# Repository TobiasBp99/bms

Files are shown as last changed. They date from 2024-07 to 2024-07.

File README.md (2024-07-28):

# bms
Project BMS (Battery Managment System) based on Texas Instruments Applicattion note [TIDA-00792](https://www.ti.com/tool/TIDA-00792).
THe design was developed during my lessons on **_Introduction to Printed Circuit Board Design_**. 

## Overview 

The BMS is a design thought for a battery supplied product where is needed some management on battery is needed to extend its life. The whole solution it's mainly implemented with parts from the same manufacturer integrated as individual modules. 

You can check more specifics details on the [PCB report](https://github.com/TobiasBp99/bms/blob/master/reportBMS.pdf).

## Features 

- Wide voltage range up to 48V
- CAN BUS to communicate with other potential modules
- Cell voltage measure
- Pack current measure
- Temperature measure
- Cell balancing
- SOH/SOC measure
- 12 to 15 cells easily adaptable

## 3D Model
- #f03c15 `Analog Front End`
- #1589F0 `Gauge`
- #1589F0 `FET'S`
- #c5f015 `Embedded System `
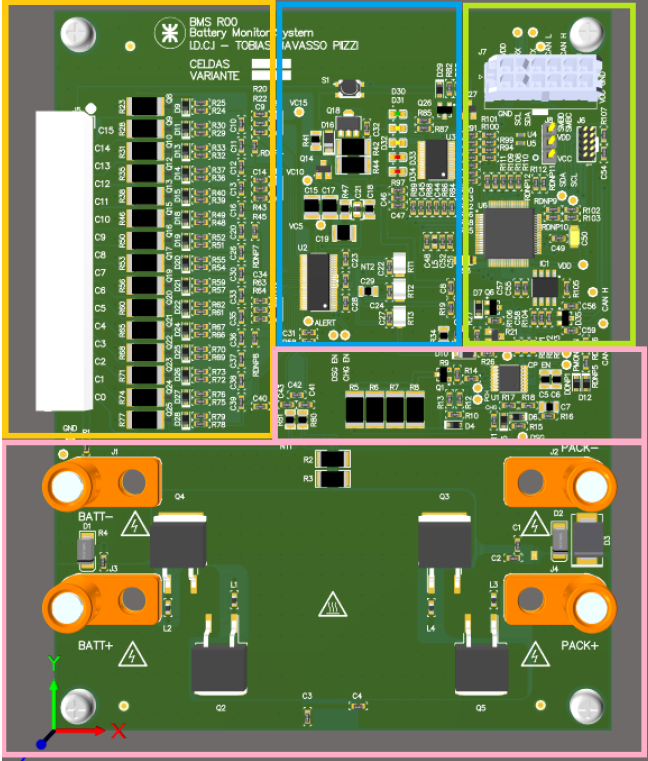
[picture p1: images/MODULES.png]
placement

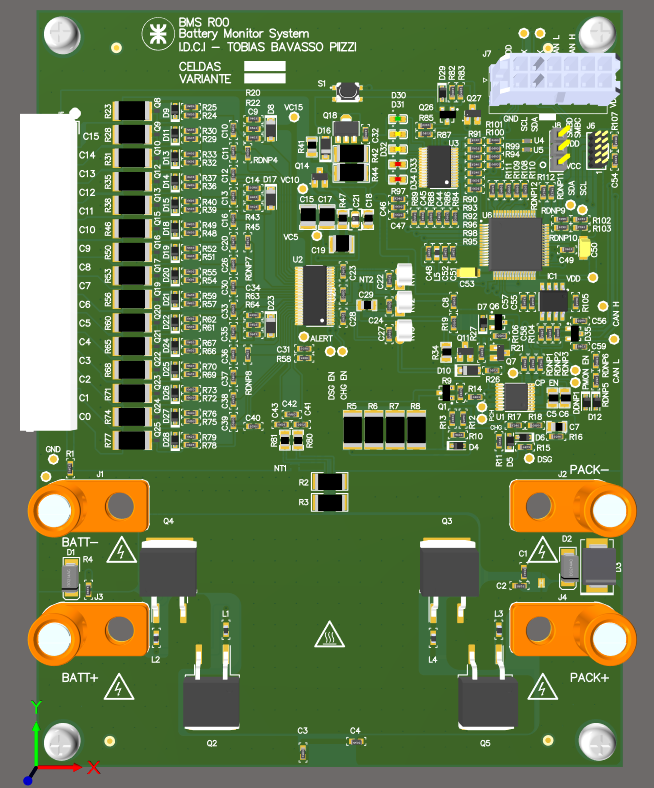
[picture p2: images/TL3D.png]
top-plane

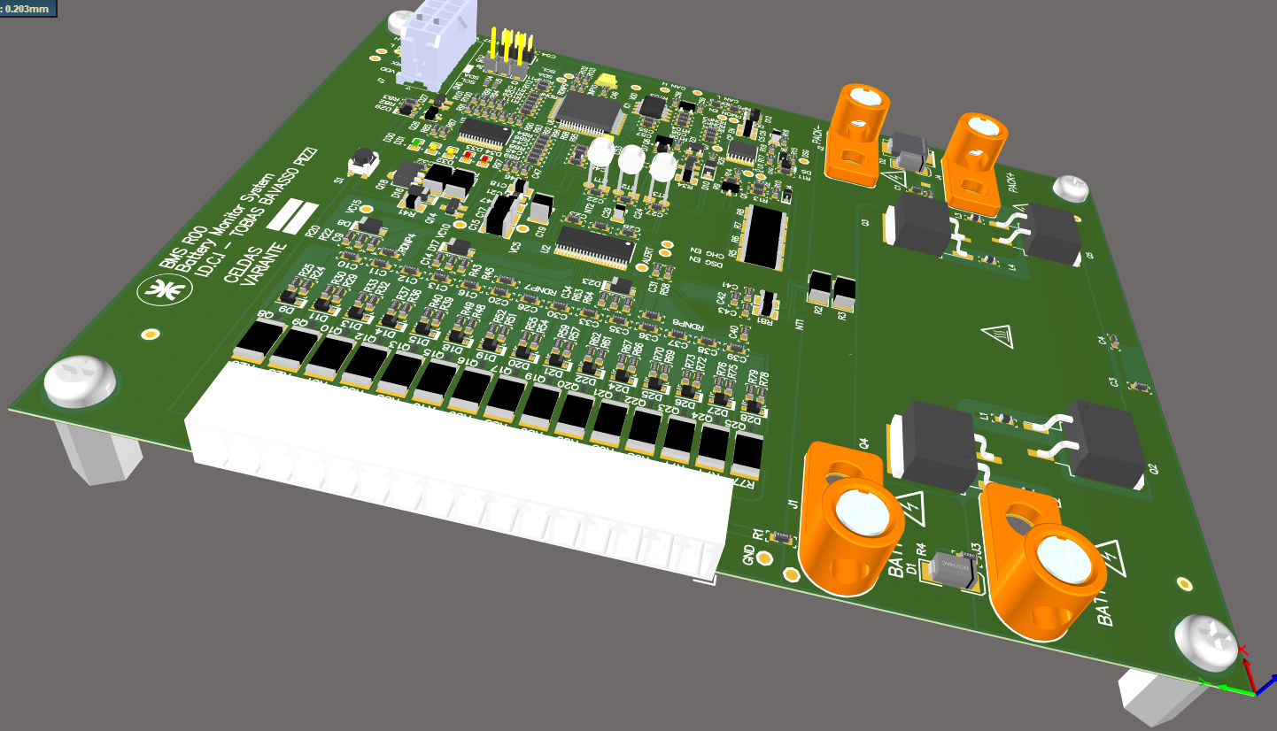
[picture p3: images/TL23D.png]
top-perspective


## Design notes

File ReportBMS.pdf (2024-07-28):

Página 1 | 21

I.D.C.I – R6575
U.T.N – F.R.B.A

# Informe de Proyecto

# “Battery Managment System”

# - Autor : Bavasso Piizzi, Tobias

# - Curso : R6575

- Docentes : Marano | , Fabio
Lozano | , Rubén

# - Curso : R6575

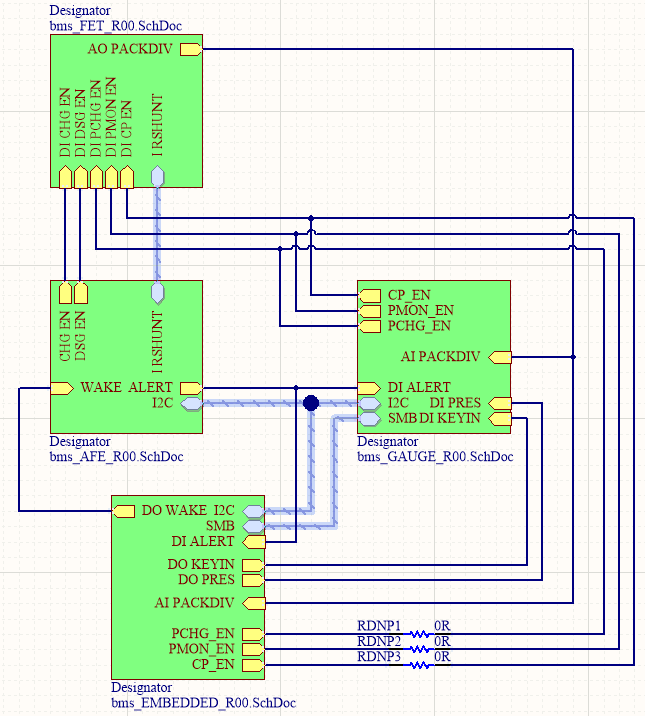
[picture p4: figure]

Página 2 | 21

# Diagrama en bloques

El diagrama en bloques de la Figura 1 corresponde al diseño del Battery Managment System (BMS), en donde se pueden identificar los bloques asociados al control de carga/descarga (FET) , front-end analógico (AFE) para el sensado del estado de cada celda, el medidor (GAUGE) encargado del procesamiento del estado de carga (SOC), estado de salud (SOH), y temperatura de la batería, al igual que el bloque del sistema embebido (EMBEDDED) para ser utilizado como gateway hacia un bus de comunicación.

Figura 1 – Diagrama en bloques

# Esquema conexionado eléctrico

El esquema eléctrico de conexionado debe conformarse mediante 4 conectores.

### Conexión Gateway

En la Figura 2, se observa al conector estipulado para operan como gateway del PCB, en donde hacia al exterior hay comunicación mediante puerto serial, protocolo I2C, Bus SMB y Bus CAN.

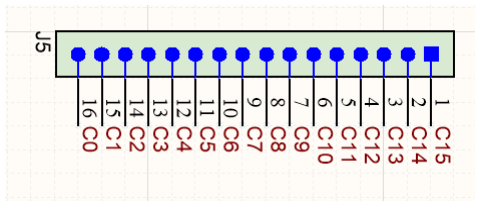
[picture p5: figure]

Página 3 | 21

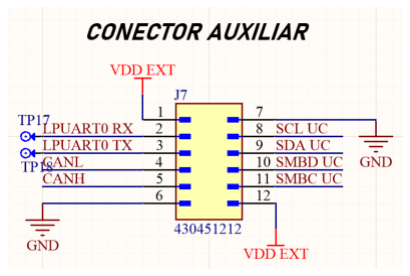
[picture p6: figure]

Figura 2 – Conector gateway

### Conexión Batería

En cuanto a las celdas de la batería tendrán un conector individualizado, en donde se tomará un cable de cada celda en serie a la batería. El diagrama de conexión se puede observar en la Figura 3.

Figura 3 – Conector celdas

### Conexión Carga

Para la carga del circuito y la batería se debe realizar el conexionado en los conectores en L o bien puede realizarse la sujeción del cable mediante un tornillo, arandela y tuerca. Estos conectores se utilizan para conectar la batería y la entrada para poder cargar la misma.

# Descripción funcional del circuito eléctrico

La funcionalidad del circuito es realizar el monitoreo para la protección de un pack de baterías de litio de 15 celdas, es decir que su tensión típica será de 48V. En este tipo de baterías es muy importante realizar constantemente la medición de su condición para evitar que su punto de trabajo sea perjudicial para prolongar su vida útil. Respecto a la funcionalidad específica de cada módulo la misma se detallará a continuación.

Página 4 | 21

### AFE

El analog front end es un nodo I2C que implementa las siguientes mediciones:
- Tensión de celda
- Corriente del pack
- Temperatura

A su vez también permite realizar el un control sobre:
- FET’s de carga y descarga
- Balanceo de cargas
Todas las mediciones realizadas son transmitidas por el bus I2C, para que los demás módulos tomen las acciones de control necesarias.

### Control de carga y descarga

Protección del tipo high-side para desconectar la batería mediante transistores en caso de haber algún inconveniente y no quitar la referencia de tensión al resto del circuito. Como características destacadas en esta etapa se pueden mencionar la carga y descarga mediante hardware independiente, al igual que la opción de realizar una pre carga a baja corriente en celdas que necesiten realizar una descarga profunda.

### Medidor

El medidor o gauge realiza todo el monitoreo de forma programable mediante SMBUS (compatilbe I2C), para no realizar el desarrollo de código en el MCU.
Este módulo se utiliza como intergaz entre el sistema embebido y el analog front end para detectar el SOC/SOH e implementar balanceos de cargas y protecciones por diversas condiciones como exceso de temperatura/tensión/corriente.
El gauge es un medidor que realiza todo el monitoreo de forma programable mediante SMBUS (compatilbe I2C), para no realizar el desarrollo de código en el MCU.

### Sistema embebido

El sistema embebido está basado en un microcontrolador que permite interconectar los módulos y otorgar una vía de salida hacia otros buses de comunicación externos.

Página 5 | 21

# BOM

El listado de partes se encuentra a continuación, para una mejor visualización se recomienda abrirlo desde el archivo generado por el software de diseño.
Com ment | Description | Designator | Footp rint | LibR ef | Qu ant ity
PIN3 | | J8 | SIP3 | PIN3 | 1
Test Point | | TP1, TP2, TP3, TP4, TP5, TP6, TP7, TP8, TP9, TP10, TP11, TP12, TP13, TP14, TP15, TP16, TP17, TP18, TP19, TP20, TP21 | TEST POINT SMD 1 | Test Point | 21
FS32 K118 LAT0 MLHT | ARM® Cortex®-M0+ series Microcontroller IC 32-Bit Single-Core 48MHz 256KB (256K x 8) FLASH 64-LQFP (10x10) | U6 | LQFP6 4-NXP | FS32 K118 LAT0 MLHT | 1
BQ76 9400 0DBT R | Battery Monitor for Lithium-Ion and Phosphate Battery Packs, DBT0044A | U2 | DBT00 44A_N | BQ76 9400 0DBT R | 1
Ferrit e Bead 1K | BLM18KG102SN1D 1K | L5 | 0603 FB | BLM1 8KG1 02SN 1D | 1
BQ76 200P WR | bq76200: Low-Power, High-Side N-channel FET Driver with Pack Voltage Monitor, PW0016A | U1 | PW00 16A_N | BQ76 200P WR | 1
1.5µF 25V X7R | Capacitor | C5 | 0805_ HV_2 | Cap 0805 _HV | 1
100n F | Capacitor | C48, C49, C51, C52, C54, C55, C57 | C0603 | Cap 0603 | 7
100n F 100V X7R | Capacitor | C1, C2, C3, C4, C46, C47 | C0603 | Cap 0603 | 6
100n F 50V X7R | Capacitor | C41, C42, C43 | C0603 | Cap 0603 | 3
100p F/50V | Capacitor | C56, C59 | C0603 | Cap 0603 | 2
10nF 100V X7R | Capacitor | C6, C7 | 0805_ HV_2 | Cap 0805 _HV | 2
10µF | Capacitor | C19 | 1210_ 270 | Cap 1210 | 1

Página 6 | 21
10µF 35V X7R | Capacitor | C15, C17 | 1210_ 270 | Cap 1210 | 2
1µF 16V X7R | Capacitor | C18 | 0805_ HV_2 | Cap 0805 _HV | 1
1µF 16V X7R | Capacitor | C21 | 0805 | Cap 0805 | 1
1µF 16V X7R | Capacitor | C23, C25, C28 | C0603 | Cap 0603 | 3
220n F 16 X7R | Capacitor | C9, C10 | C0603 | Cap 0603 | 2
220n F 16V X7R | Capacitor | C11, C12, C13, C14, C16, C20, C26, C30, C32, C33, C34, C35, C36, C37, C38, C39, C40 | C0603 | Cap 0603 | 17
3.3nF 25V X7R | Capacitor | C44, C45 | C0603 | Cap 0603 | 2
39nF | Capacitor | C58 | C0603 | Cap 0603 | 1
4.7µF 10V X7R | Capacitor | C29 | 0805_ HV_2 | Cap 0805 _HV | 1
4700 pF 50V X7R | Capacitor | C22, C24, C27 | C0603 | Cap 0603 | 3
470p F 50V X7R | Capacitor | C8, C31 | C0603 | Cap 0603 | 2
BQ78 350D BTR-R1 | CEDV Li-Ion Gas Gauge and Battery Management Controller Companion to the bq769x0 Battery Monitoring AFE, DBT0030A | U3 | DBT00 30A_N | BQ78 350D BTR-R1 | 1
L35 | Connector, L Type Copper Single Conductor, TH | J1, J2, J3, J4 | TB_L3 5 | L35 | 4
1N41 48W-7-F | Diode, Ultrafast, 100V, 0.15A, SOD-123 | D8, D10, D16, D17, D23 | SOD-123 | 1N41 48W-7-F | 5
ES3D -E3/57 T | Diode, Ultrafast, 200V, 3A, SMC | D3 | SMC | ES3D -E3/57 T | 1

Página 7 | 21
MMS Z522 8BS-7-F | Diode, Zener, 3.9 V, 200 mW, SOD-323 | D12, DDNP1 | sod-323 | MMS Z522 8BS-7-F | 2
MMS Z523 2BS-7-F | Diode, Zener, 5.6V, 200mW, SOD-323 | D9, D11, D13, D14, D15, D18, D19, D20, D21, D22, D24, D25, D26, D27, D28 | sod-323 | MMS Z523 2BS-7-F | 15
MMS Z524 6BS-7-F | Diode, Zener, 16 V, 200 mW, SOD-323 | D4, D5, D6 | sod-323 | MMS Z524 6BS-7-F | 3
MMS Z524 8BS-7-F | Diode, Zener, 18 V, 200 mW, SOD-323 | D7, D29 | sod-323 | MMS Z524 8BS-7-F | 2
NUP2 105L | Dual Line CAN Bus Protector TVS DIODE 24VWM 44VC SOT23-3 | D35 | SOT-23 | NUP2 105L | 1
TPD1 E10B 06DP YT | ESD Protection in 0402 Package with 10 pF Capacitance and 6 V Breakdown, 1 Channel, -40 to +125 degC, 2-pin X2SON (DPY) | U4, U5 | DPY00 02A | TPD1 E10B 06DP YT | 2
BLM1 8SG2 21TN 1D | Ferrite Bead, 220 ohm @ 100 MHz, 2.5 A, 0603 | L1, L2, L3, L4 | 0603 FB | BLM1 8SG2 21TN 1D | 4
Fiduc ial | Fiducial mark. There is nothing to buy or mount. | FID1, FID2, FID3, FID4 | Fiduci al10-20 | Fiduc ial_1 | 4
TJA14 41xx | High-speed CAN transceiver | IC1 | SOIC8 | TJA14 41xx | 1
LED GREE N | LED G | D30 | LED06 03-G | LED GREE N | 1
LED RED | LED R | D33, D34 | LED06 03-R | LED RED | 2
LED YELL OW | LED Y | D31, D32 | LED06 03-Y | LED YELL OW | 2
NY PMS 440 0025 PH | Machine Screw, Round, #4-40 x 1/4, Nylon, Philips panhead | H1, H2, H3, H4 | NY PMS 440 0025 PH | NY PMS 440 0025 PH | 4
4304 5121 2 | Micro-Fit 3.0 43045 CONN HEADER VERT 12POS 3MM | J7 | MOLE X_430 45121 2 | 4304 5121 2 | 1

Página 8 | 21
BSS1 23 | MOSFET, N-CH, 100V, 0.17A, SOT-23 | Q7, Q11, Q27 | SOT-23 | BSS1 23 | 3
BST8 2,215 | MOSFET, N-CH, 100 V, 0.19 A, SOT-23 | Q14 | SOT-23 | BST8 2,215 | 1
CSD1 9536 KTT | MOSFET, N-CH, 100 V, 200 A, KTT0002A | Q2, Q3, Q4, Q5 | KTT00 02A_N | CSD1 9536 KTT | 4
CSD1 3381 F4 | MOSFET, N/P-CH, 12 V, 2.1 A, 1.0x0.35x0.6mm | Q8, Q9, Q10, Q12, Q13, Q15, Q16, Q17, Q19, Q20, Q21, Q22, Q23, Q24, Q25 | YJC00 03A | CSD1 3381 F4 | 15
ZXMP 10A1 3FTA | MOSFET, P-CH, -100V, -0.6A, SOT-23 | Q1, Q6, Q26 | SOT-23 | ZXMP 10A1 3FTA | 3
HEAD ER5x 2-1.27 mm | PAD10-2X05-HH | J6 | PAD10 -2X05-HH | HEAD ER5x 2-1.27 mm | 1
10uF/ 16V | Polarized Capacitor Tantalium | C50, C53 | 1206 Cap Tant | Cap Pol Tanta lio | 2
0.0R 0.5% | Resistor | RDNP4, RDNP7, RDNP8 | R0603 | Res | 3
0R | Resistor | RDNP1, RDNP2, RDNP3, RDNP9, RDNP10, RDNP11, RDNP12 | R0603 | Res | 7
0R 0.5% | Resistor | R1, R4, R18, R98, R99 | R0603 | Res | 5
1.00K 1% | Resistor | R44 | 2010 | Res | 1
1.0K 5% | Resistor | R20, R22, R25, R30, R33, R37, R40, R43, R45, R49, R52, R55, R59, R62, R63, R64, R67, R70, R73, R76, R79, R94, R95, RDNP5, RDNP6 | R0603 | Res | 25
1.0M 5% | Resistor | R21, R96 | R0603 | Res | 2
1.0m R 1% | Resistor | R2, R3 | 2010 | Res | 2
1.2K 5% | Resistor | R5, R6, R7, R8 | 2512 | Res | 4
10.0K | Resistor | R102, R103 | R0603 | Res | 2
10.0K 0.1% | Resistor | R88, R89 | R0603 | Res | 2
10.0K 5% | Resistor | R24, R29, R32, R36, R39, R48, R51, R54, R57, R61, R66, R69, R72, R75, R78 | R0603 | Res | 15

Página 9 | 21
10.0 M 1% | Resistor | R9, R10, R11, R19, R27 | R0603 | Res | 5
100.0 K 1% | Resistor | R34, R41, R47 | 0805_ HV_2 | Res | 3
100.0 K 5% | Resistor | R82, R90, R97 | R0603 | Res | 3
100.0 R 1% | Resistor | R12, R16, R17 | R0603 | Res | 3
100.0 R 5% | Resistor | R100, R101 | R0603 | Res | 2
100R 1% | Resistor | R80, R81 | 0805_ HV_2 | Res 0805 _HV | 2
113.0 K 1% | Resistor | R93 | R0603 | Res | 1
12.0K | Resistor | R107, R108, R109, R110, R111, R112 | R0603 | Res | 6
220.0 K | Resistor | R83 | R0603 | Res | 1
28.7R 1% | Resistor | R23, R28, R31, R35, R38, R46, R50, R53, R56, R60, R65, R68, R71, R74, R77 | 2512 | Res | 15
300.0 K 25pp m/°C | Resistor | R84, R85, R86, R87 | R0603 | Res | 4
4.7K | Resistor | R105 | R0603 | Res | 1
499.0 K 1% | Resistor | R58 | R0603 | Res | 1
51.0K 5% | Resistor | R26 | R0603 | Res | 1
510.0 K 5% | Resistor | R91, R92 | R0603 | Res | 2
61.9R | Resistor | R104, R106 | R0603 | Res | 2
620.0 R 5% | Resistor | R13, R14, R15 | R0603 | Res | 3
750.0 R 5% | Resistor | R42 | 2010 | Res | 1
N/A | Spark Gap | E1 | SPARK _GAP2 | Spark Gap | 1
1902 C | Standoff, Hex, 0.5"L #4-40 Nylon | H5, H6, H7, H8 | Keysto ne_19 02C | 1902 C | 4
PTS8 15 | SWITCH TACTILE SPST-NO 0.05A 12V | S1 | PTS81 5SJK2 50SMT RLFS | PTS8 15 | 1
3950 2101 1 | Terminal block, 3.5mm, 16x1, R/A, TH | J5 | HEAD ER_39 | 3950 2101 6 | 1

Página 10 | 21
| | | 50210 16
103A T-2 | Thermistor NTC, 10.0k ohm, 1%, Disc, 5x8.4 mm | RT1, RT2, RT3 | Therm istor_1 03AT-2 | 103A T-2 | 3
ZXTN 1910 0CZT A | Transistor, NPN, 100 V, 5.25 A, SOT-89 | Q18 | SOT-89-3 | ZXTN 1910 0CZT A, Diod es Inc. | 1
SMAJ 60CA | TVS DIODE 22VWM 35.5VC DO214AC. BIDIRECCIONAL | D1, D2 | DO-214AB (SMA) | SMAJ 60CA | 2

# Hojas de datos

Los 3 (tres) circuitos integrados principales que conforman el PCB son parte del portfolio para manejo de baterías del proveedor Texas Instruments.
Se recomienda revisar la documentación más detallada del fabricante.

BQ76200
Para revisar la documentación en mayor profundidad se recomienda revisar el enlace del Datasheet. (https://www.ti.com/product/es-mx/BQ76200)

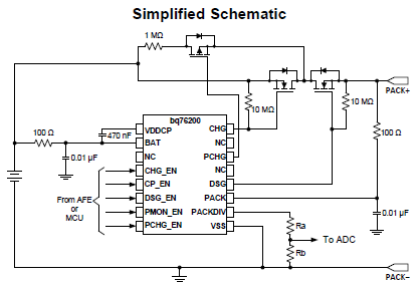
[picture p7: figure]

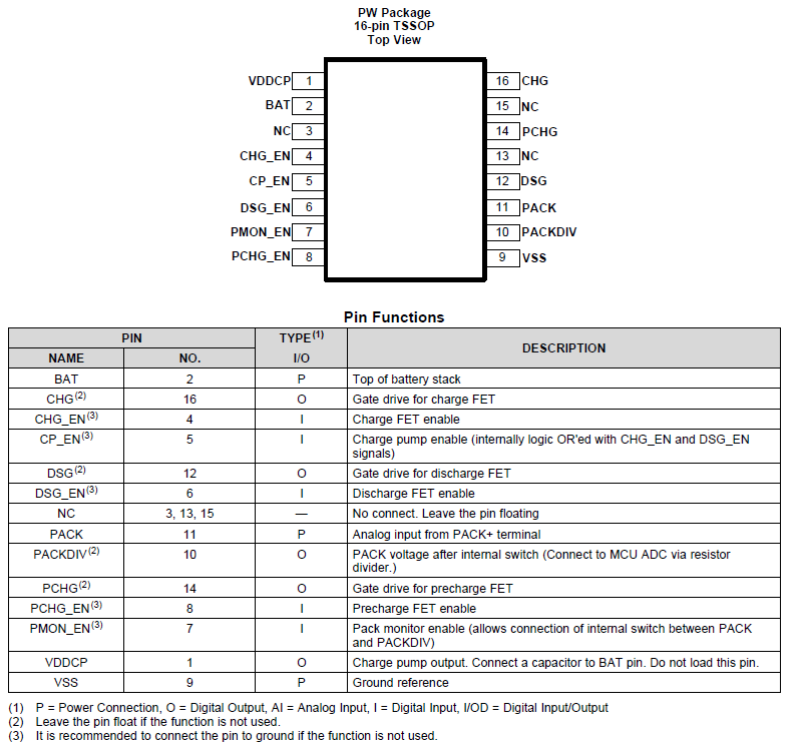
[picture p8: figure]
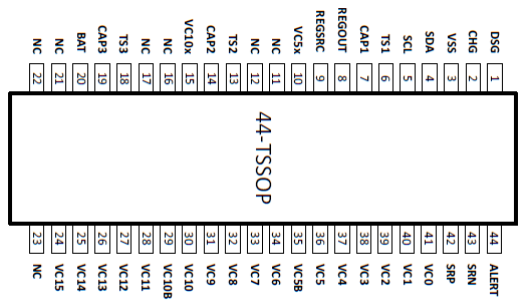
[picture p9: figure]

Página 11 | 21

Figura 4 – BQ76200 resumen datasheet BQ76940
Para revisar la documentación en mayor profundidad se recomienda revisar el enlace del Datasheet. (https://www.ti.com/product/es-mx/BQ76940)

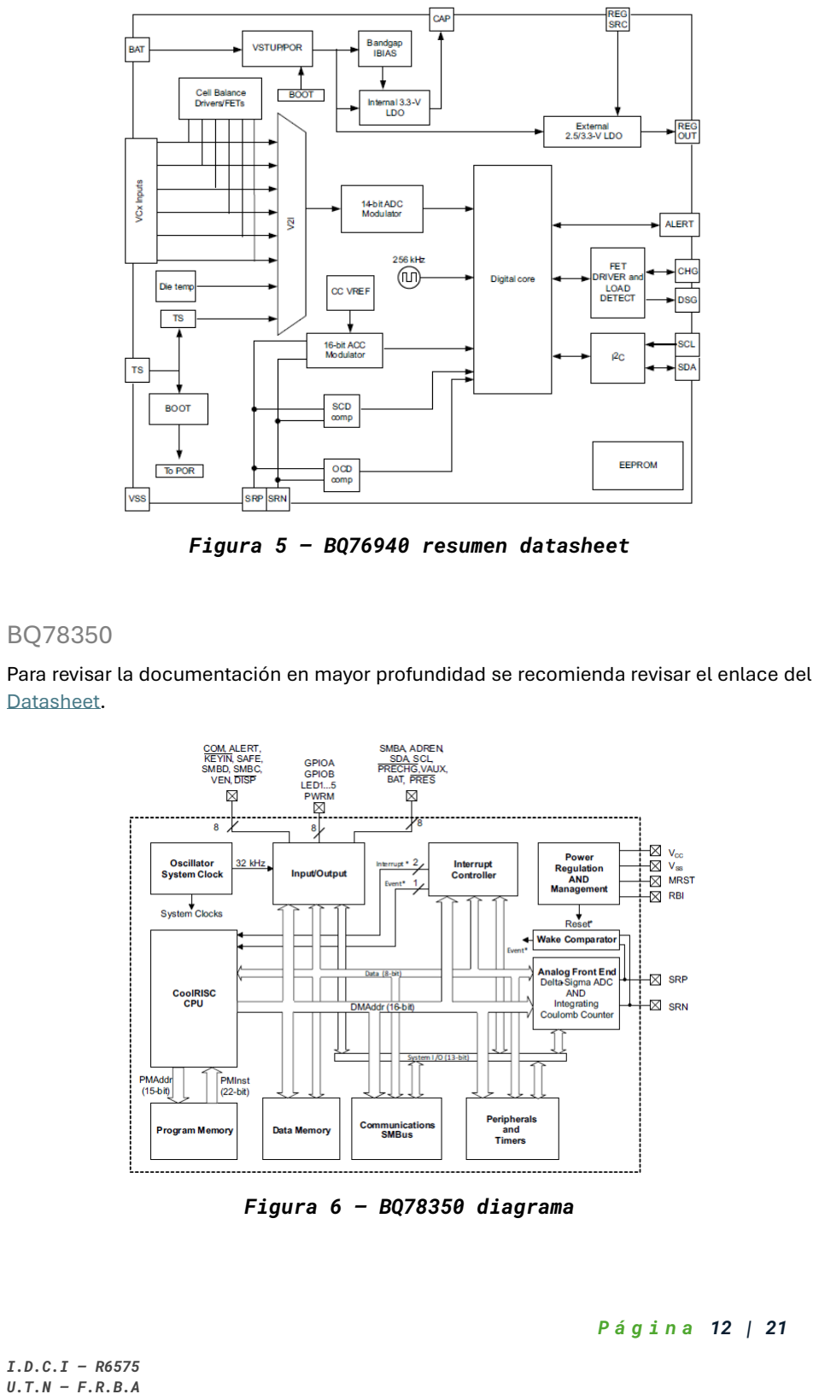
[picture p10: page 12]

Página 12 | 21

Figura 5 – BQ76940 resumen datasheet

BQ78350
Para revisar la documentación en mayor profundidad se recomienda revisar el enlace del Datasheet. (https://www.ti.com/product/es-mx/BQ78350-R1A)

Figura 6 – BQ78350 diagrama

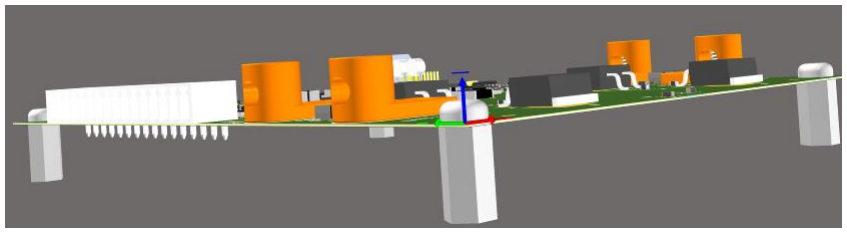
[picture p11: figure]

Página 13 | 21

# Ancho de trazas

### Señales

Las trazas denominadas de señal, o dicho de otra forma que no requieren ningún cuidado en particular fueron utilizadas con un ancho mínimo de 0.2 mm, siendo 0.254mm el valor típico utilizado.

### Batería

Las trazas asociadas al conexionado de cada celda en la batería se realizaron mediante un polígono, a fin de disminuir al máximo posible la impedancia en las mismas, a su vez como el conector se ubicó directamente enfrentado a un juego de resistencias que sirve para ecualizar las cargas de la celda en caso de ser necesario, cuyo chip resistor es R2512 no habría motivo alguno para limitar el tamaño de las conexiones.

### Carga

Finalmente, todo el conexionado del circuito de carga fue dimensionado para manejar cargas de aproximadamente 30Ah, este tipo de pistas fueron implementadas también con polígonos por cuestiones de disipación térmica, si bien los transistores son perfectamente capaces de soportar la exigencia del diseño con el uso de los polígonos se evita la aparición de puntos calientes en el trazado del circuito.

# Restricciones mecánicas y sujeción

La sujeción del PCB se realizará mediante 4 agujeros de sujeción del tipo M3, se recomienda utilizar unos separados roscados para sujetar la placa como se indica en la Figura 7. Sin embargo, tranquilamente se podría utilizar un gabinete aprovechando los agujeros de sujeción.

Figura 7 – Sujeción

Mecánicamente la única restricción mecánica que cuenta el PCB se debe a los conectores para la carga de batería. El footprint colocado corresponde al montaje de un conector igual al compartido en la Figura 8.

Página 14 | 21

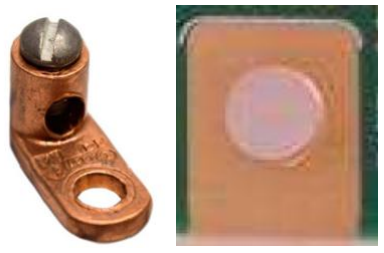
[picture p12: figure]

Figura 8 – Conector L35 Figura 9 – Footrprint La flexibilidad que aporta el footprint es que permite obviar el montaje del conector y realizar el conexionado con un tornillo y tuerca.

# Perforado

Tal como se mencionó anteriormente el perforado de los agujeros de sujeción deben ser realizados con un diámetro de 3.2mm para poder utilizar tornillos con rosca métrica M3. Luego el perforado de las vías se utilizaron dos estilos como template, en ambos casos se utilizó la misma relación de aspecto entre el diámetro del agujero y su corona.

Las vías utilizadas son las siguientes:

Diámetro | 0.3 mm | 0.4 mm
Corona | 0.6 mm | 0.8 mm

Como todos los componentes se encuentran ubicados en la cara superior del PCB, se aprovecha dicha distribución para realizar el cableado de la etapa de carga y descarga con el menor cambio de caras posibles, entonces prácticamente las vías utilizadas en los polígonos son simplemente para poder manejar el calor generado.

# Reglas CAD

A continuación, se comparten las reglas configuradas para realizar el diseño del BMS.

### Clearance

Para las reglas de la separación entre trazas se utilizaron dos reglas, una genérica para todas las trazas, y otra más restrictiva para mantener una separación mayor con los polígonos.

Página 15 | 21

Figura 10 – Reglas de separación

### Width

El ancho de las trazas también fue separado en dos reglas, una general y otra particular para utilizarse en las pistas que son para alimentar circuitos integrados, o parte del módulo de los transistores FET´s.

Figura 11 – Reglas de ancho

### Polígonos

Todos los polígonos están conectados mediante un termal relief, a excepción de las vías correspondientes al mismo y los transistores de potencia en donde se utilizó el estilo de conexión directa.

# Proveedor

Para la fabricación de las placas se seleccionó a un proveedor del exterior, PCBWay para ser más específico para corroborar que el proveedor tenga las capacidades de fabricación se simuló la carga de los archivos gerbers en la web, arrojando las siguientes características del diseño, las cuales coinciden con las mencionadas previamente.

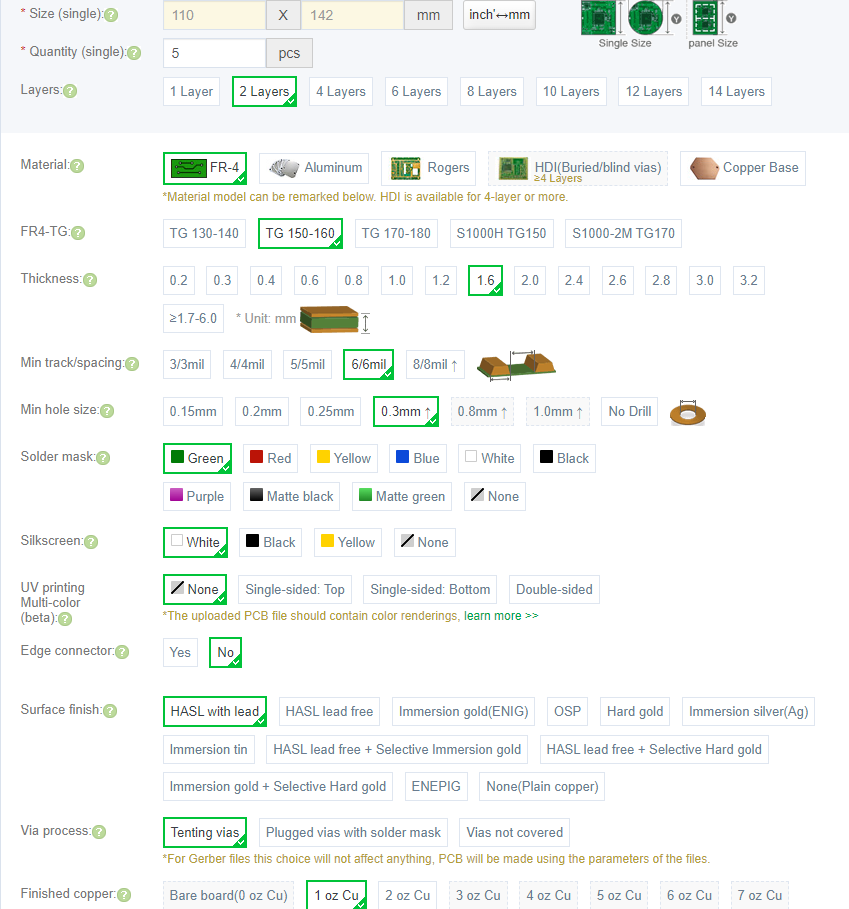
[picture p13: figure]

Página 16 | 21

Figura 12 – Capacidades del proveedor

# Consideraciones ruteo

Si bien múltiples cuestiones asociadas al ruteo fueron mencionadas a lo largo del documento, hay ciertas cuestiones que aún merece la pena ser destacado.
Por ejemplo hay una resistencia dentro del circuito de carga que funciona como resistencia de shunt para sensar la corriente de la batería. Esta resistencia fue ruteada al estilo de resistencia de 4 terminales para evitar introducir ruido en la medición. En la Figura 13 Se puede observar el ruteo.

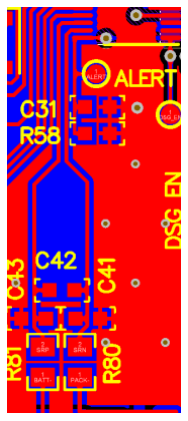
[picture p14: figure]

Figura 13 – Resistencia shunt

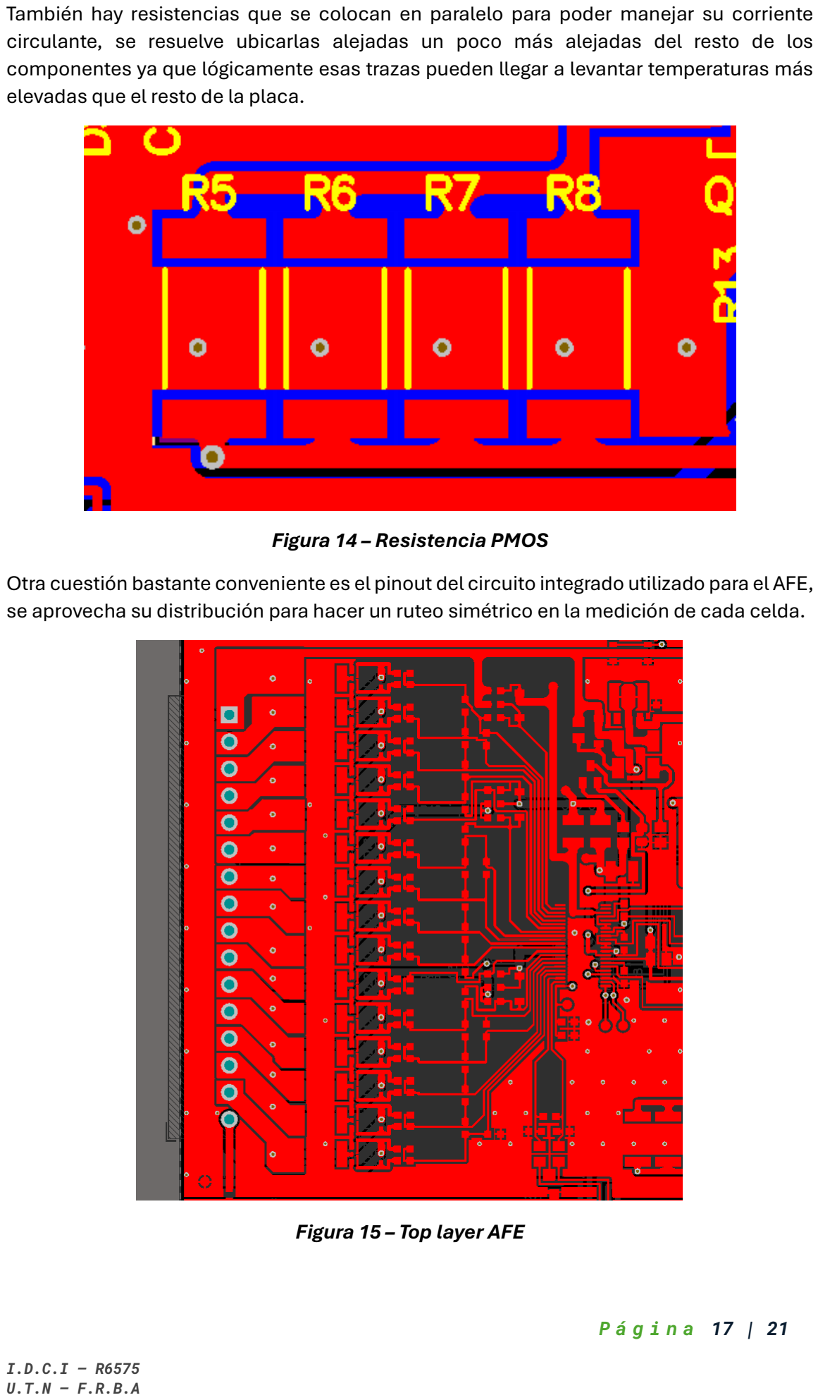
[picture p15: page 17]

Página 17 | 21

También hay resistencias que se colocan en paralelo para poder manejar su corriente circulante, se resuelve ubicarlas alejadas un poco más alejadas del resto de los componentes ya que lógicamente esas trazas pueden llegar a levantar temperaturas más elevadas que el resto de la placa.

Figura 14 – Resistencia PMOS Otra cuestión bastante conveniente es el pinout del circuito integrado utilizado para el AFE, se aprovecha su distribución para hacer un ruteo simétrico en la medición de cada celda.

Figura 15 – Top layer AFE

Página 18 | 21

# Montaje y soldadura

El montaje de los componentes será realizado mediante una máquina pick and place a excepción de los 6 conectores de la placa los cuales serán insertados manualmente en una segunda etapa.
Una vez colocados los componentes SMD en su totalidad del top layer se realizará el proceso de soldado con un horno de refusión, siendo esta la primera etapa de soldado. Luego se insertarán manualmente los conectores para su posterior soldado por la técnica de ola.

# Disposición

Los componentes fueron acomodados según la disposición indicada en la Figura 17, allí se puede evidenciar la búsqueda de agrupar los componentes de cada módulo en un área delimitada, permitiendo mayor flexibilidad a la hora de interconectar las trazas tal como se observan en el diagrama en bloques.
Se puede identificar a los bloques según su color recuadrado.
Módulo | Color
Amarillo | AFE
Azul | Gauge
Verde | Embebido + conector de comunicación
Rosa | FET’s

También vale la pena mencionar que todos los conectores se encuentran en los bordes de la placa para ser accedidos fácilmente a la hora de realizar el conexionado correspondiente.
Por último, también vale la pena destacar la ubicación de los conectores de entrada para realizar la carga del pack de batería y tratando de que aleje lo más posible de los circuitos que manejan niveles lógicos menores, como por ejemplo el microcontrolador.

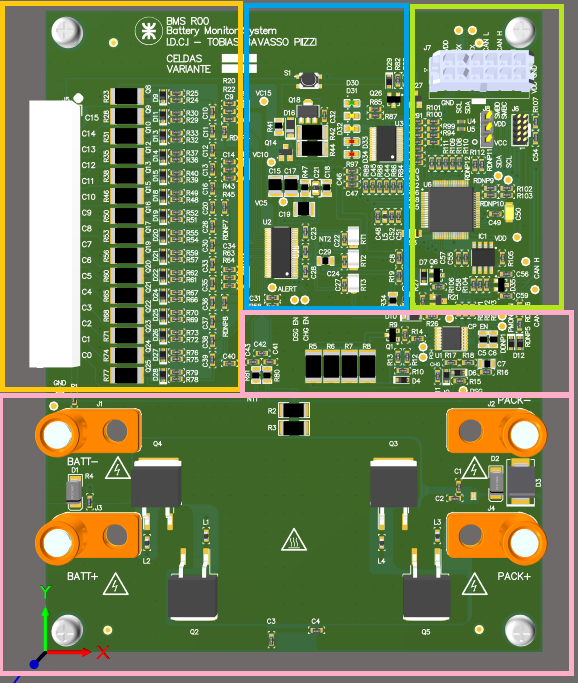
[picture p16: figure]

Página 19 | 21

Figura 18 – Disposición

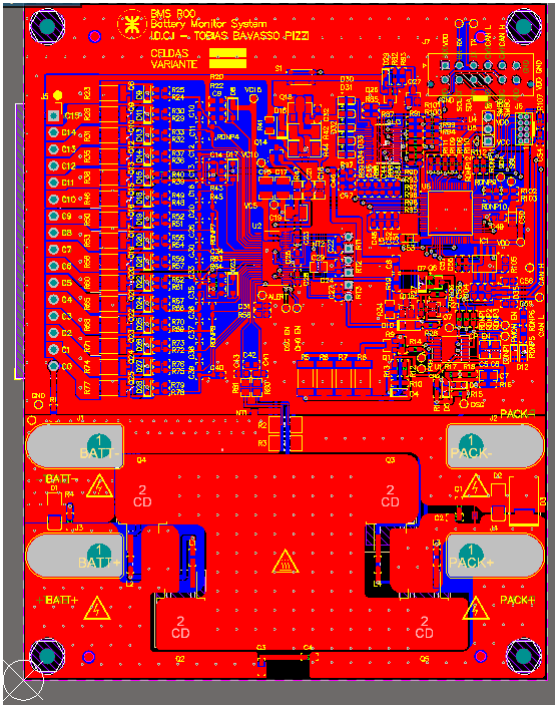
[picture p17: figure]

Página 20 | 21

# Impreso terminado

Se comparten a continuación en las Figuras 19 Y 20 El impreso finalizado.

Figura 19 – Vista superior

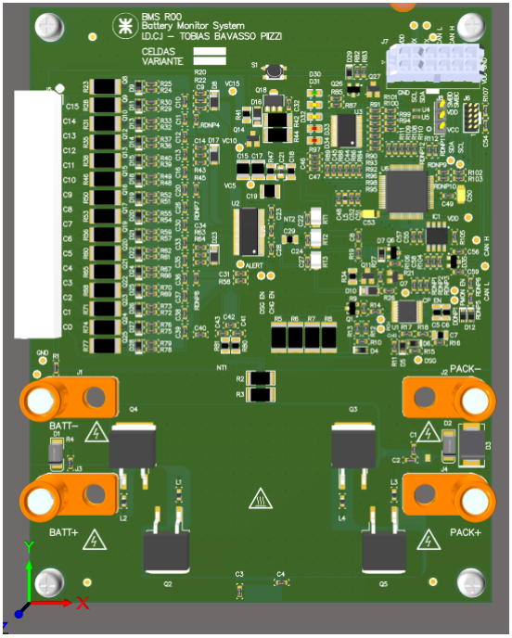
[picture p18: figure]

Página 21 | 21

Figura 20 – Vista superior 3D

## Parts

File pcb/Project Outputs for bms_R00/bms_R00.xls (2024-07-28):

Comment | Description | Designator | Footprint | LibRef | Quantity
PIN3 |  | J8 | SIP3 | PIN3 | 1
Test Point |  | TP1, TP2, TP3, TP4, TP5, TP6, TP7, TP8, TP9, TP10, TP11, TP12, TP13, TP14, TP15, TP16, TP17, TP18, TP19, TP20, TP21 | TEST POINT SMD 1 | Test Point | 21
FS32K118LAT0MLHT | ARM® Cortex®-M0+ series Microcontroller IC 32-Bit Single-Core 48MHz 256KB (256K x 8) FLASH 64-LQFP (10x10) | U6 | LQFP64-NXP | FS32K118LAT0MLHT | 1
BQ7694000DBTR | Battery Monitor for Lithium-Ion and Phosphate Battery Packs, DBT0044A | U2 | DBT0044A_N | BQ7694000DBTR | 1
Ferrite Bead 1K | BLM18KG102SN1D 1K | L5 | 0603 FB | BLM18KG102SN1D | 1
BQ76200PWR | bq76200: Low-Power, High-Side N-channel FET Driver with Pack Voltage Monitor, PW0016A | U1 | PW0016A_N | BQ76200PWR | 1
1.5µF 25V X7R | Capacitor | C5 | 0805_HV_2 | Cap 0805_HV | 1
100nF | Capacitor | C48, C49, C51, C52, C54, C55, C57 | C0603 | Cap 0603 | 7
100nF 100V X7R | Capacitor | C1, C2, C3, C4, C46, C47 | C0603 | Cap 0603 | 6
100nF 50V X7R | Capacitor | C41, C42, C43 | C0603 | Cap 0603 | 3
100pF/50V | Capacitor | C56, C59 | C0603 | Cap 0603 | 2
10nF 100V X7R | Capacitor | C6, C7 | 0805_HV_2 | Cap 0805_HV | 2
10µF | Capacitor | C19 | 1210_270 | Cap 1210 | 1
10µF 35V X7R | Capacitor | C15, C17 | 1210_270 | Cap 1210 | 2
1µF 16V X7R | Capacitor | C18 | 0805_HV_2 | Cap 0805_HV | 1
1µF 16V X7R | Capacitor | C21 | 0805 | Cap 0805 | 1
1µF 16V X7R | Capacitor | C23, C25, C28 | C0603 | Cap 0603 | 3
220nF 16 X7R | Capacitor | C9, C10 | C0603 | Cap 0603 | 2
220nF 16V X7R | Capacitor | C11, C12, C13, C14, C16, C20, C26, C30, C32, C33, C34, C35, C36, C37, C38, C39, C40 | C0603 | Cap 0603 | 17
3.3nF 25V X7R | Capacitor | C44, C45 | C0603 | Cap 0603 | 2
39nF | Capacitor | C58 | C0603 | Cap 0603 | 1
4.7µF 10V X7R | Capacitor | C29 | 0805_HV_2 | Cap 0805_HV | 1
4700pF 50V X7R | Capacitor | C22, C24, C27 | C0603 | Cap 0603 | 3
470pF 50V X7R | Capacitor | C8, C31 | C0603 | Cap 0603 | 2
BQ78350DBTR-R1 | CEDV Li-Ion Gas Gauge and Battery Management Controller Companion to the bq769x0 Battery Monitoring AFE, DBT0030A | U3 | DBT0030A_N | BQ78350DBTR-R1 | 1
L35 | Connector, L Type Copper Single Conductor, TH | J1, J2, J3, J4 | TB_L35 | L35 | 4
1N4148W-7-F | Diode, Ultrafast, 100V, 0.15A, SOD-123 | D8, D10, D16, D17, D23 | SOD-123 | 1N4148W-7-F | 5
ES3D-E3/57T | Diode, Ultrafast, 200V, 3A, SMC | D3 | SMC | ES3D-E3/57T | 1
MMSZ5228BS-7-F | Diode, Zener, 3.9 V, 200 mW, SOD-323 | D12, DDNP1 | sod-323 | MMSZ5228BS-7-F | 2
MMSZ5232BS-7-F | Diode, Zener, 5.6V, 200mW, SOD-323 | D9, D11, D13, D14, D15, D18, D19, D20, D21, D22, D24, D25, D26, D27, D28 | sod-323 | MMSZ5232BS-7-F | 15
MMSZ5246BS-7-F | Diode, Zener, 16 V, 200 mW, SOD-323 | D4, D5, D6 | sod-323 | MMSZ5246BS-7-F | 3
MMSZ5248BS-7-F | Diode, Zener, 18 V, 200 mW, SOD-323 | D7, D29 | sod-323 | MMSZ5248BS-7-F | 2
NUP2105L | Dual Line CAN Bus Protector TVS DIODE 24VWM 44VC SOT23-3 | D35 | SOT-23 | NUP2105L | 1
TPD1E10B06DPYT | ESD Protection in 0402 Package with 10 pF Capacitance and 6 V Breakdown, 1 Channel, -40 to +125 degC, 2-pin X2SON (DPY) | U4, U5 | DPY0002A | TPD1E10B06DPYT | 2
BLM18SG221TN1D | Ferrite Bead, 220 ohm @ 100 MHz, 2.5 A, 0603 | L1, L2, L3, L4 | 0603 FB | BLM18SG221TN1D | 4
Fiducial | Fiducial mark. There is nothing to buy or mount. | FID1, FID2, FID3, FID4 | Fiducial10-20 | Fiducial_1 | 4
TJA1441xx | High-speed CAN transceiver | IC1 | SOIC8 | TJA1441xx | 1
LED GREEN | LED G | D30 | LED0603-G | LED GREEN | 1
LED RED | LED R | D33, D34 | LED0603-R | LED RED | 2
LED YELLOW | LED Y | D31, D32 | LED0603-Y | LED YELLOW | 2
NY PMS 440 0025 PH | Machine Screw, Round, #4-40 x 1/4, Nylon, Philips panhead | H1, H2, H3, H4 | NY PMS 440 0025 PH | NY PMS 440 0025 PH | 4
430451212 | Micro-Fit 3.0 43045 CONN HEADER VERT 12POS 3MM | J7 | MOLEX_430451212 | 430451212 | 1
BSS123 | MOSFET, N-CH, 100V, 0.17A, SOT-23 | Q7, Q11, Q27 | SOT-23 | BSS123 | 3
BST82,215 | MOSFET, N-CH, 100 V, 0.19 A, SOT-23 | Q14 | SOT-23 | BST82,215 | 1
CSD19536KTT | MOSFET, N-CH, 100 V, 200 A, KTT0002A | Q2, Q3, Q4, Q5 | KTT0002A_N | CSD19536KTT | 4
CSD13381F4 | MOSFET, N/P-CH, 12 V, 2.1 A, 1.0x0.35x0.6mm | Q8, Q9, Q10, Q12, Q13, Q15, Q16, Q17, Q19, Q20, Q21, Q22, Q23, Q24, Q25 | YJC0003A | CSD13381F4 | 15
ZXMP10A13FTA | MOSFET, P-CH, -100V, -0.6A, SOT-23 | Q1, Q6, Q26 | SOT-23 | ZXMP10A13FTA | 3
HEADER5x2-1.27mm | PAD10-2X05-HH | J6 | PAD10-2X05-HH | HEADER5x2-1.27mm | 1
10uF/16V | Polarized Capacitor Tantalium | C50, C53 | 1206 Cap Tant | Cap Pol Tantalio | 2
0.0R 0.5% | Resistor | RDNP4, RDNP7, RDNP8 | R0603 | Res | 3
0R | Resistor | RDNP1, RDNP2, RDNP3, RDNP9, RDNP10, RDNP11, RDNP12 | R0603 | Res | 7
0R 0.5% | Resistor | R1, R4, R18, R98, R99 | R0603 | Res | 5
1.00K 1% | Resistor | R44 | 2010 | Res | 1
1.0K 5% | Resistor | R20, R22, R25, R30, R33, R37, R40, R43, R45, R49, R52, R55, R59, R62, R63, R64, R67, R70, R73, R76, R79, R94, R95, RDNP5, RDNP6 | R0603 | Res | 25
1.0M 5% | Resistor | R21, R96 | R0603 | Res | 2
1.0mR 1% | Resistor | R2, R3 | 2010 | Res | 2
1.2K 5% | Resistor | R5, R6, R7, R8 | 2512 | Res | 4
10.0K | Resistor | R102, R103 | R0603 | Res | 2
10.0K 0.1% | Resistor | R88, R89 | R0603 | Res | 2
10.0K 5% | Resistor | R24, R29, R32, R36, R39, R48, R51, R54, R57, R61, R66, R69, R72, R75, R78 | R0603 | Res | 15
10.0M 1% | Resistor | R9, R10, R11, R19, R27 | R0603 | Res | 5
100.0K 1% | Resistor | R34, R41, R47 | 0805_HV_2 | Res | 3
100.0K 5% | Resistor | R82, R90, R97 | R0603 | Res | 3
100.0R 1% | Resistor | R12, R16, R17 | R0603 | Res | 3
100.0R 5% | Resistor | R100, R101 | R0603 | Res | 2
100R 1% | Resistor | R80, R81 | 0805_HV_2 | Res 0805_HV | 2
113.0K 1% | Resistor | R93 | R0603 | Res | 1
12.0K | Resistor | R107, R108, R109, R110, R111, R112 | R0603 | Res | 6
220.0K | Resistor | R83 | R0603 | Res | 1
28.7R 1% | Resistor | R23, R28, R31, R35, R38, R46, R50, R53, R56, R60, R65, R68, R71, R74, R77 | 2512 | Res | 15
300.0K 25ppm/°C | Resistor | R84, R85, R86, R87 | R0603 | Res | 4
4.7K | Resistor | R105 | R0603 | Res | 1
499.0K 1% | Resistor | R58 | R0603 | Res | 1
51.0K 5% | Resistor | R26 | R0603 | Res | 1
510.0K 5% | Resistor | R91, R92 | R0603 | Res | 2
61.9R | Resistor | R104, R106 | R0603 | Res | 2
620.0R 5% | Resistor | R13, R14, R15 | R0603 | Res | 3
750.0R 5% | Resistor | R42 | 2010 | Res | 1
N/A | Spark Gap | E1 | SPARK_GAP2 | SparkGap | 1
1902C | Standoff, Hex, 0.5"L #4-40 Nylon | H5, H6, H7, H8 | Keystone_1902C | 1902C | 4
PTS815 | SWITCH TACTILE SPST-NO 0.05A 12V | S1 | PTS815SJK250SMTRLFS | PTS815 | 1
395021011 | Terminal block, 3.5mm, 16x1, R/A, TH | J5 | HEADER_395021016 | 395021016 | 1
103AT-2 | Thermistor NTC, 10.0k ohm, 1%, Disc, 5x8.4 mm | RT1, RT2, RT3 | Thermistor_103AT-2 | 103AT-2 | 3
ZXTN19100CZTA | Transistor, NPN, 100 V, 5.25 A, SOT-89 | Q18 | SOT-89-3 | ZXTN19100CZTA, Diodes Inc. | 1
SMAJ60CA | TVS DIODE 22VWM 35.5VC DO214AC. BIDIRECCIONAL | D1, D2 | DO-214AB(SMA) | SMAJ60CA | 2
